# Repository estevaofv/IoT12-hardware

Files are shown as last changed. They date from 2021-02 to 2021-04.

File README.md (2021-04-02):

# Status

**Experimental. Do not replicate.**

**You should be present at all times when using this circuit in case something goes wrong.**

# IoT12-hardware
Schematic and PCB files of the IoT12 solder iron temperature controller for T12 tips.

My [Kicad library](https://github.com/atoomnetmarc/ATOOMNETKICAD) is used in this project.

Control Board:\
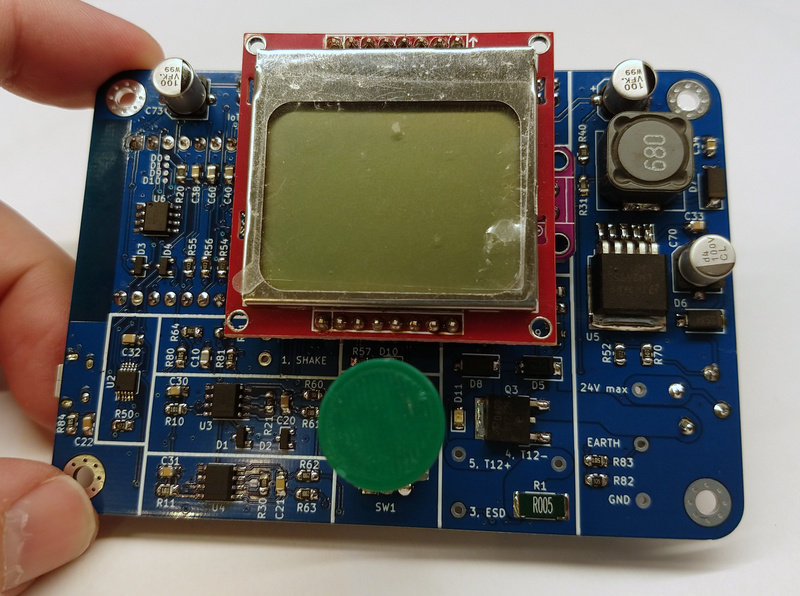
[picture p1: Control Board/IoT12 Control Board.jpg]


Power Supply:\
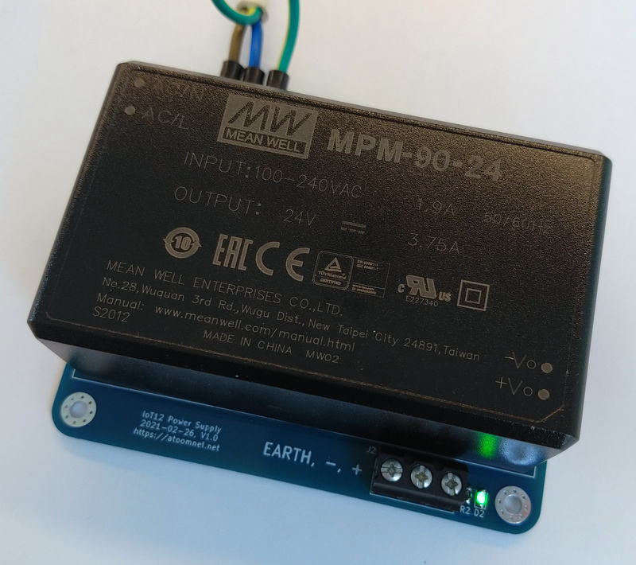
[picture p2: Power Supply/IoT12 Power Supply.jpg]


# Checklist

:ballot_box_with_check:Design schematic\
:ballot_box_with_check:Route V1 control board PCB\
:ballot_box_with_check:Slept a few days before ordering V1 control board PCB\
:ballot_box_with_check:Order V1 control board PCB\
:ballot_box_with_check:Made my first github repository\
:ballot_box_with_check:V1 control board PCB arrived\
:ballot_box_with_check:Solder V1 control board PCB and make assembly instructions\
:ballot_box_with_check:Observe that there is something wrong in schematic\
:ballot_box_with_check:Debug V1 control board PCB\
:ballot_box_with_check:Redesign control board PCB, add microcontroller\
:ballot_box_with_check:Order V2 control board PCB\
:ballot_box_with_check:Design power supply PCB\
:ballot_box_with_check:Order power supply PCB\
:ballot_box_with_check:V2 control board PCB and power supply PCB arrived\
:ballot_box_with_check:Solder V2 control board PCB and make assembly instructions\
:ballot_box_with_check:Solder V1 power supply PCB and make assembly instructions\
:black_square_button:Debug V2 control board PCB\
:ballot_box_with_check:Start making firmware\
:black_square_button:Finish first firmware version\
:black_square_button:...\
:black_square_button:profit

# Checklist V2.0 control PCB

Worky (after bodge fix)?

:ballot_box_with_check:SAMD21 debug LED\
:ballot_box_with_check:SAMD21 USB device\
:ballot_box_with_check:SAMD21 SWD\
:ballot_box_with_check:SAMD21 TP1/D0\
:ballot_box_with_check:SAMD21 TP2/D1\
:ballot_box_with_check:SAMD21 TP3/D9\
:ballot_box_with_check:SAMD21 TP4/D10\
:ballot_box_with_check:SAMD21 HEAT_INT\
:ballot_box_with_check:SAMD21 HEAT_PWM\
:ballot_box_with_check:SAMD21 I2C minion\
:ballot_box_with_check:SAMD21 I2S_GAIN0\
:ballot_box_with_check:SAMD21 I2S_GAIN1\
:ballot_box_with_check:SAMD21 I2S_SD\
:ballot_box_with_check:SAMD21 ADC_RDY\
:ballot_box_with_check:SAMD21 I2C ADC\
:ballot_box_with_check:SAMD21 I2C ADC NTC\
:ballot_box_with_check:SAMD21 I2C ADC TEMP\
:ballot_box_with_check:SAMD21 I2C ADC VIN\
:ballot_box_with_check:SAMD21 I2C ADC IRON_CURRENT\
:ballot_box_with_check:SAMD21 I2C EEPROM\
:ballot_box_with_check:SAMD21 ADC NTC\
:ballot_box_with_check:SAMD21 ADC TEMP\
:ballot_box_with_check:SAMD21 ADC VIN\
:ballot_box_with_check:SAMD21 ADC IRON_CURRENT\
:ballot_box_with_check:SAMD21 ADC AIN_COMP\
:ballot_box_with_check:SAMD21 AC AIN_COMP\
:ballot_box_with_check:ESP32 LCD_LED\
:ballot_box_with_check:ESP32 ROT_SW\
:ballot_box_with_check:ESP32 ROT_A\
:ballot_box_with_check:ESP32 ROT_B\
:ballot_box_with_check:ESP32 I2S\
:ballot_box_with_check:ESP32 I2C\
:ballot_box_with_check:ESP32 JTAG\
:ballot_box_with_check:ESP32 LCD\
:ballot_box_with_check:ESP32 HEAT_INT

# Changelog

**Control board PCB version V2.1**

- Swapped SDA/SCL I2C minion pins on heater controller.
- Swapped SDA/SCL I2C master pins on heater controller.
- Renamed PWM_HEAT to HEAT_PWM.
- Re-added MAX809S voltage monitor to keep ESP32 in reset if 3.3V is too low.
- Dimensioned F1 to 50% of Amax of T12-tip, see notes in schematic.
- Connected Vin ADC to after F1.

**Control board PCB version V2.0**

- Replace safety features by microcontroller.
- Heating control now done by microcontroller.
- Changed shape and layout of pcb.

**Control board PCB version V1.1**

- Added explanation to schematic about using matched resistors for the instrumentation amplifiers.
- Changed gain resistors of the instrumentation amplifiers as to keep Vout under 1V at full scale input.
- Added series diode to output of voltage monitor.
- Lowered value of C2-C5 from 10nF to 1nF.
- Added D9 and D10.
- Changed value of R9 from 100R to 1k
- Added circuit to shutdown heating in case of overheating tip.

**Control board PCB version V1.0**

- First version that got made into PCB form.

# Eratta

**Control board PCB version V2.1**

- No known erratum.

**Control board PCB version V2.0**

- I2C to heater controller not working. SDA/SCL are swapped. Swap them on the PCB near R55 and R56 to make the ESP32 communicate to the heater controller.
- A theme is developing :unamused:. I2C from the heater controller to the I2C EEPROM and ADC is not working. SDA/SCL are swapped. Swap them between R53, R54 and the heater controller on the bottom where the SDA/SCL traces run next to each other.
- ESP32 will lockup if power supply rise time is too slow.

**Control board PCB version V1.1**

- Overheating circuit not very stable. No fix.

**Control board PCB version V1.0**

- Silkscreen error in 'Solder iron connector'-block. '5, red, +.' and '4, black, ground.' are switched resulting in negative voltages for positive temperatures. Switch leads will solve this. Corrected in next PCB version.
- Gain of instrumentation amplifiers not correct.
- Programming by USB is impossible.
- Measuring temperature takes too long (20ms).



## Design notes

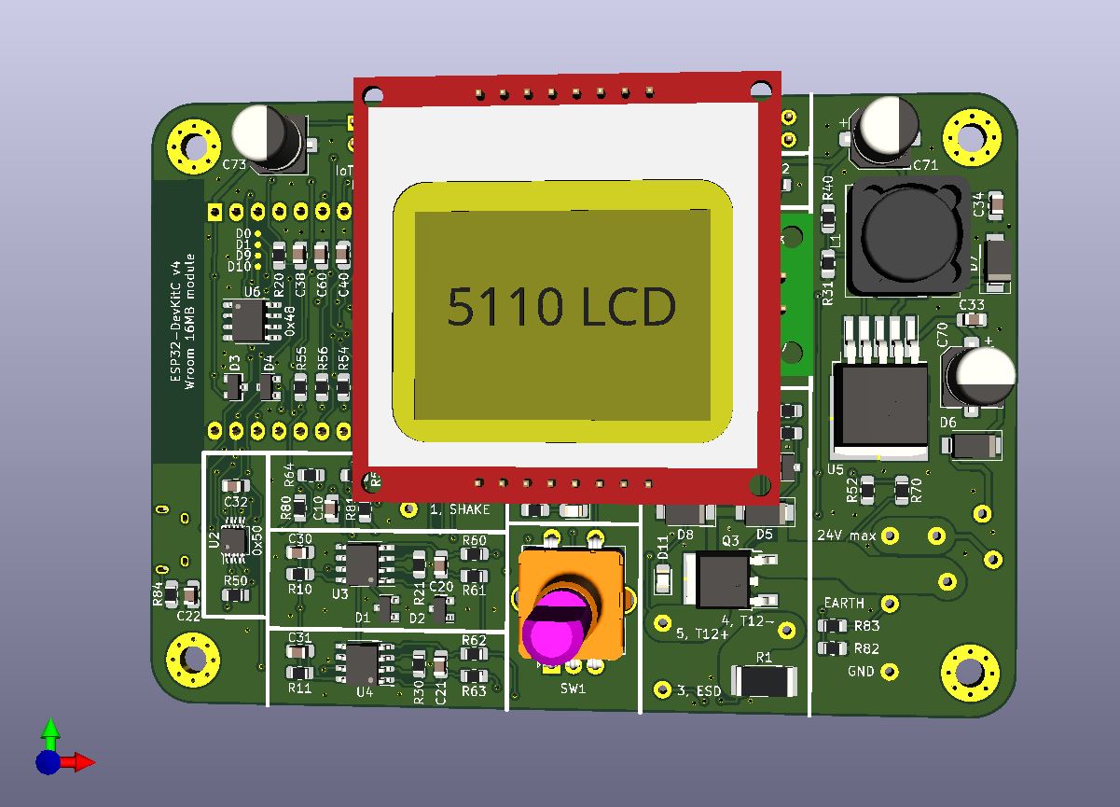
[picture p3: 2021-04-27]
Control Board/IoT12 Control Board-render.jpg

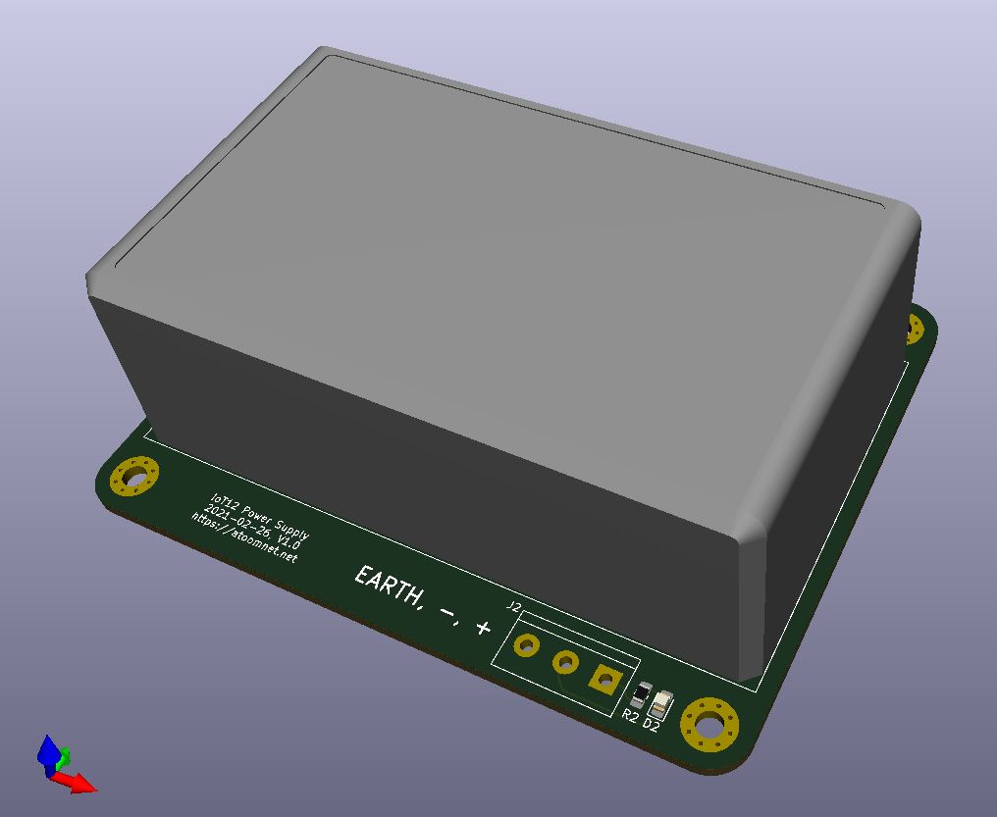
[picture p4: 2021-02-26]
Power Supply/IoT12 Power Supply-render.jpg

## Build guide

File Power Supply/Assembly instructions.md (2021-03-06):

# Solder

Solder components in the following order.
Use the [interactive BOM](bom/ibom.html) for values and positions of the components.

## Resistor

R2.

## Diode

D2.

## Screw terminal

J1, J2.

## Power supply

One off PS1, PS2 or PS3.

# Testing

⚡ ☠️ **Warning**! When testing you are  (mm|planck distances|inches) away from dangerous mains voltage. When touched it hurts the entire time you are dying. The bottom and top the PCB contain exposed tracks and screw terminals carrying mains voltage. Consult expert on how to handle mains voltages.

**You must use a wall socket that is protected by some kind of [Residual Current Device (RCD)](https://en.wikipedia.org/wiki/Residual-current_device)** that breaks the connection to mains voltage in the unfortunate event you touch live wires.

Place bottom of PCB on isolating material.

Connect leads of a mains cable to J1. Use the correct screw terminal for the correct mains line. If top of PCB is not clear enough, use labels on bottom of PCB and/or consult the PCB design files.

⚡ Connect the mains cable to the wall socket.

Notice the green LED lighting up. Now carefully measure the low voltage side on screw terminal J2. You should measure 24V volts (if you mounted a Mean Well MPM-90-24).

Disconnect the mains cable from the wall socket. Notice that the green LED is still lit. It will stop emitting light after some unit of time. The capacitors in the Mean Well power supply still contain some chare and are discharging slowly.

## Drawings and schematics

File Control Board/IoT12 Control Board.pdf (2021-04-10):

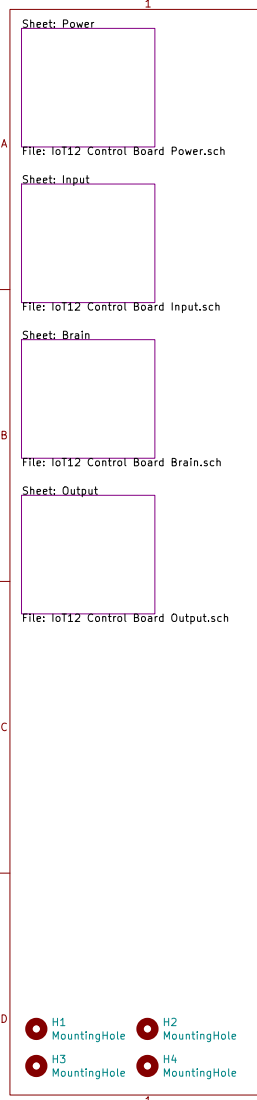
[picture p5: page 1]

File: IoT12 Control Board Input.sch Sheet: Power File: IoT12 Control Board Power.sch Sheet: Brain File: IoT12 Control Board Brain.sch Sheet: Output

File: IoT12 Control Board Output.sch H2MountingHole H4MountingHole H3MountingHole H1MountingHole

File: IoT12 Control Board.sch Sheet: /
Id: 1/5 Title: IoT12-hardware

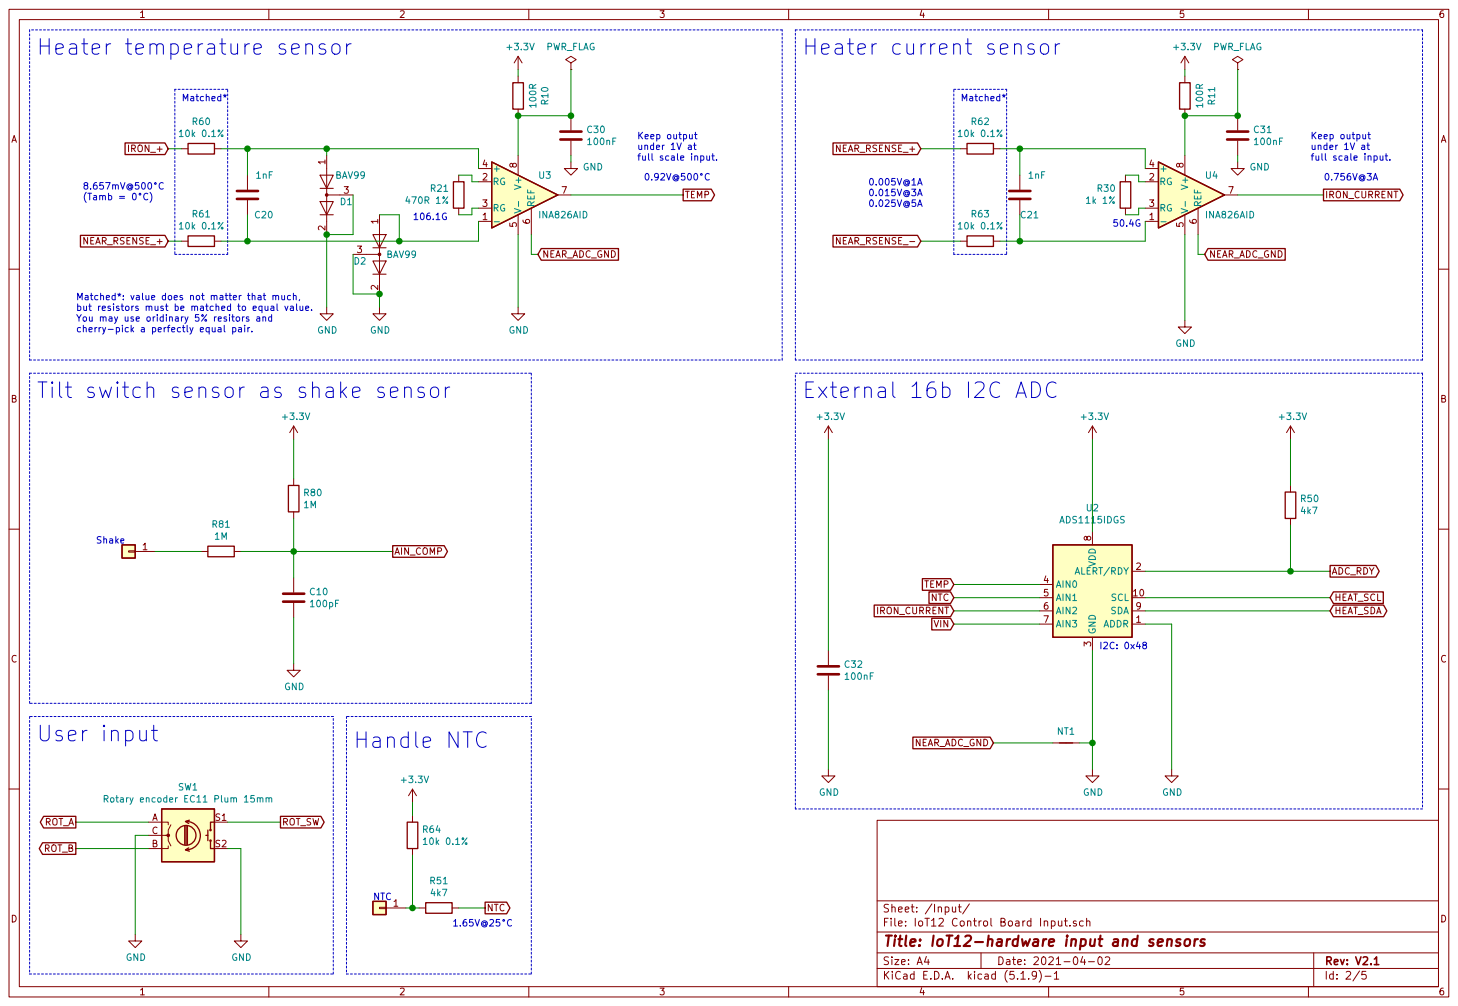
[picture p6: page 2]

Keep output under 1V at

Matched*: value does not matter that much, but resistors must be matched to equal value.

You may use oridinary 5% resitors and

1.65V@25°C Tilt switch sensor as shake sensor

Sheet: /Input/
File: IoT12 Control Board Input.sch
Id: 2/5 Title: IoT12-hardware input and sensors

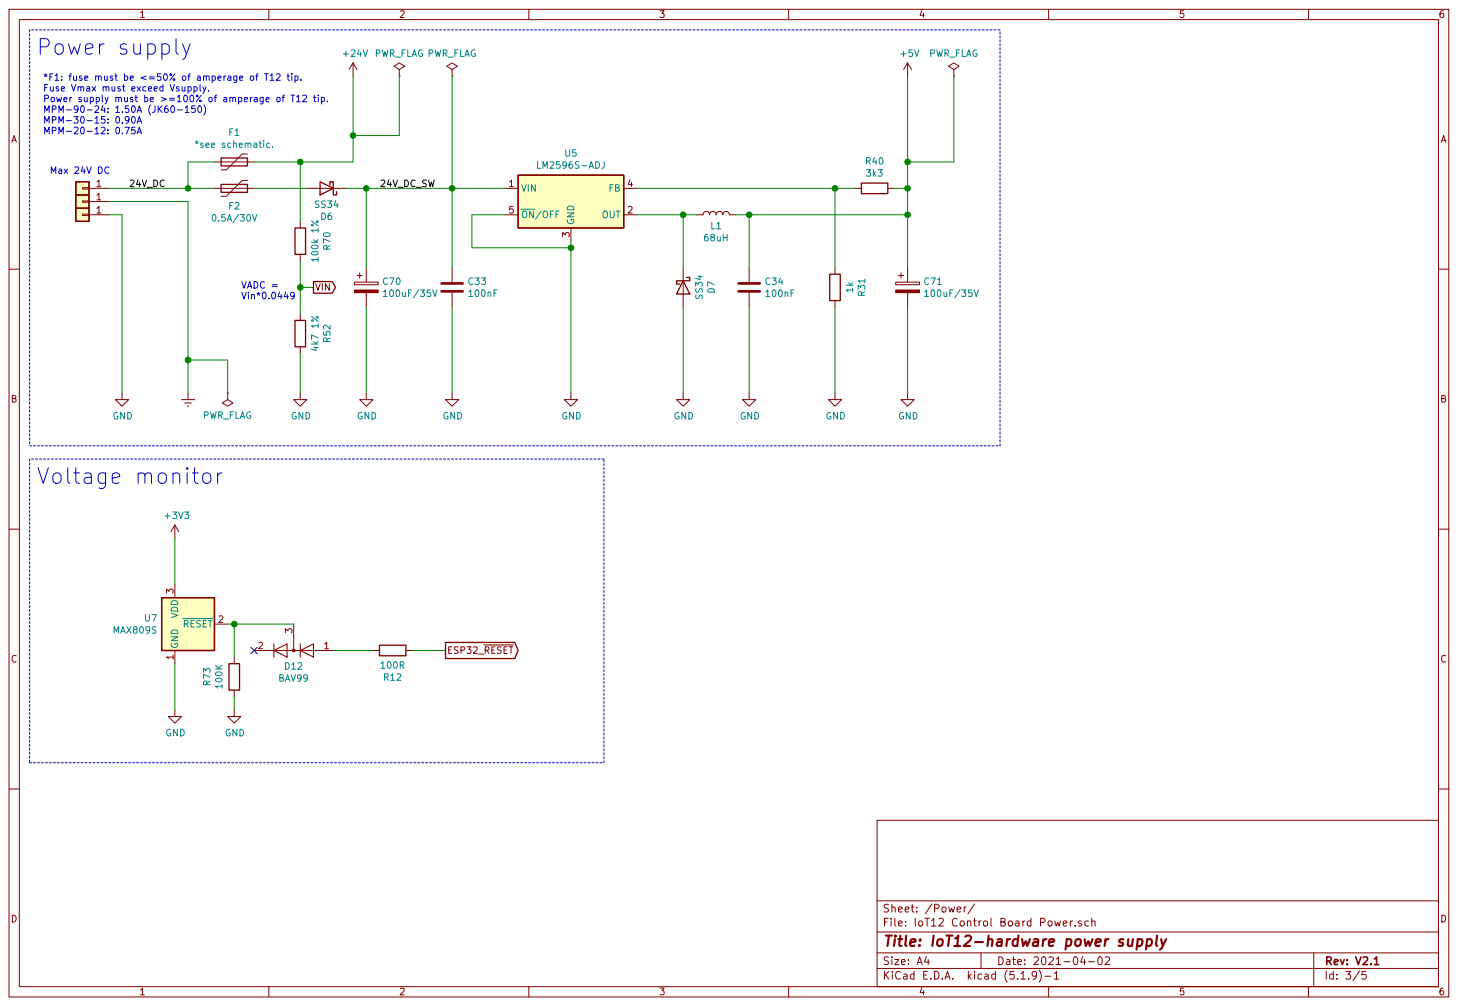
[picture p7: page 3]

MPM-90-24: 1.50A (JK60-150) MPM-30-15: 0.90A MPM-20-12: 0.75A Power supply
File: IoT12 Control Board Power.sch Sheet: /Power/ GND

*F1: fuse must be <=50% of amperage of T12 tip.
Fuse Vmax must exceed Vsupply.
Power supply must be >=100% of amperage of T12 tip.

VADC = Vin*0.0449 Max 24V DC Voltage monitor

Id: 3/5 Title: IoT12-hardware power supply

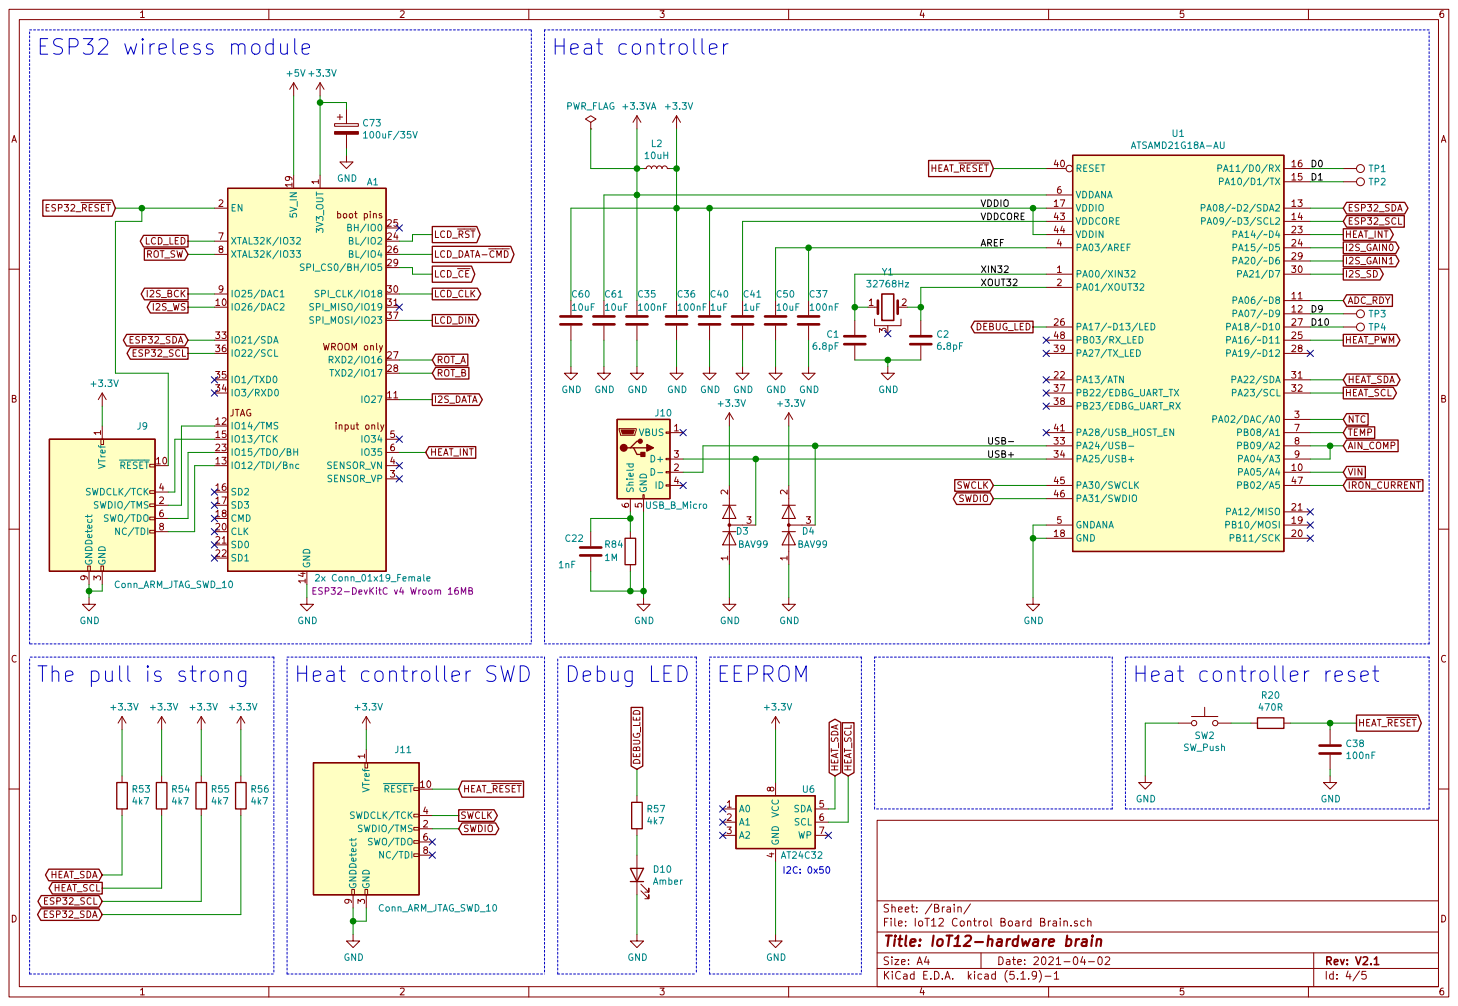
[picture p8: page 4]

3 SWDCLK/TCK 4 SWO/TDO 6 NC/TDI 8 GNDDetect 9

4 SDA 5 SCL 6 WP 7 VCC

File: IoT12 Control Board Brain.sch Sheet: /Brain/
Id: 4/5 Title: IoT12-hardware brain

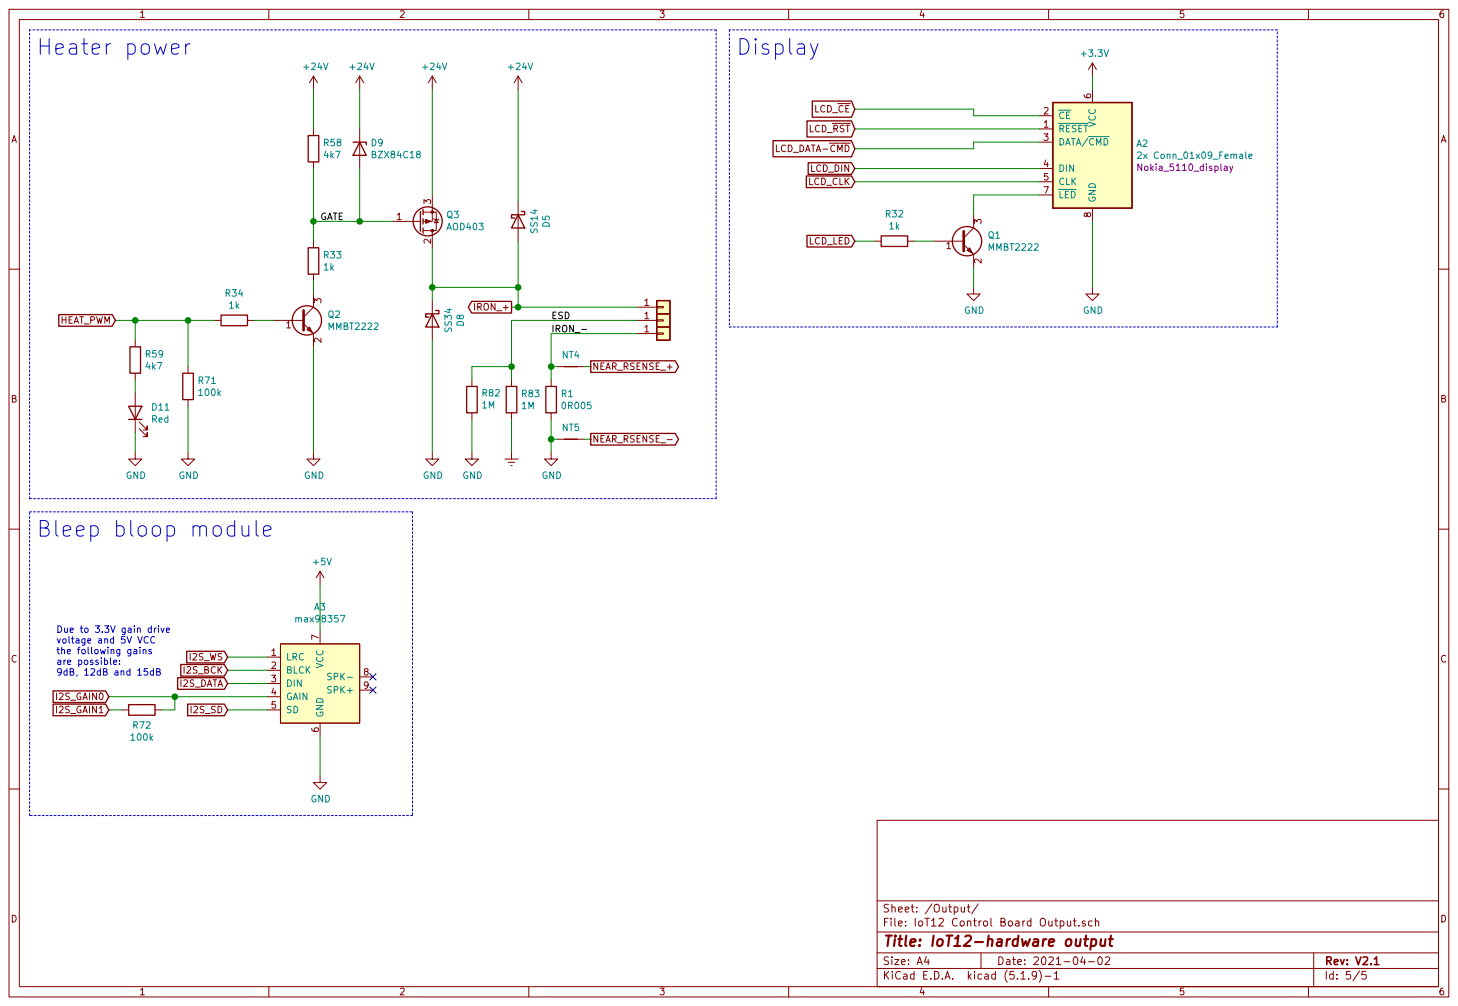
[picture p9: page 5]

are possible: 9dB, 12dB and 15dB Heater power

Due to 3.3V gain drive
voltage and 5V VCC
the following gains

Sheet: /Output/
File: IoT12 Control Board Output.sch
Id: 5/5 Title: IoT12-hardware output

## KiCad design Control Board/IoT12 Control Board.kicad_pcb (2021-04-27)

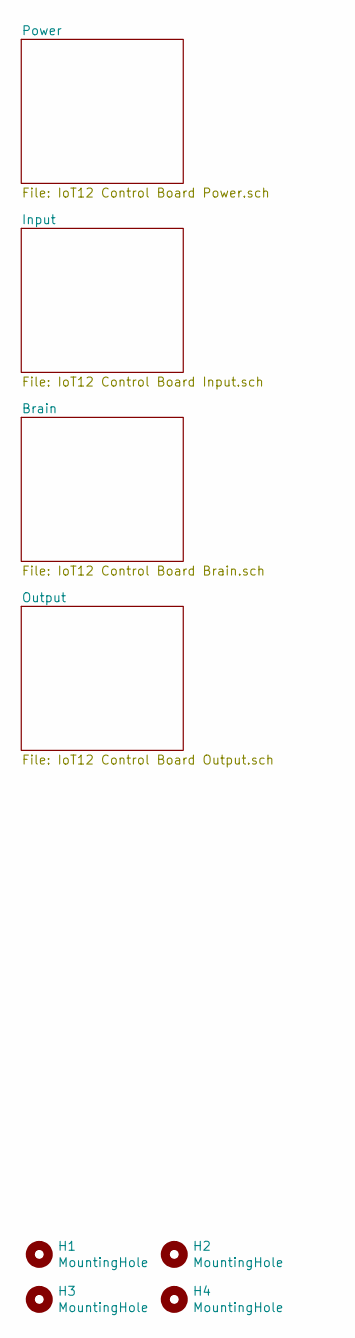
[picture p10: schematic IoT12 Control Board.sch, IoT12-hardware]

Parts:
H1, H2, H3, H4: MountingHole; MountingHole_3.2mm_M3_Pad_Via

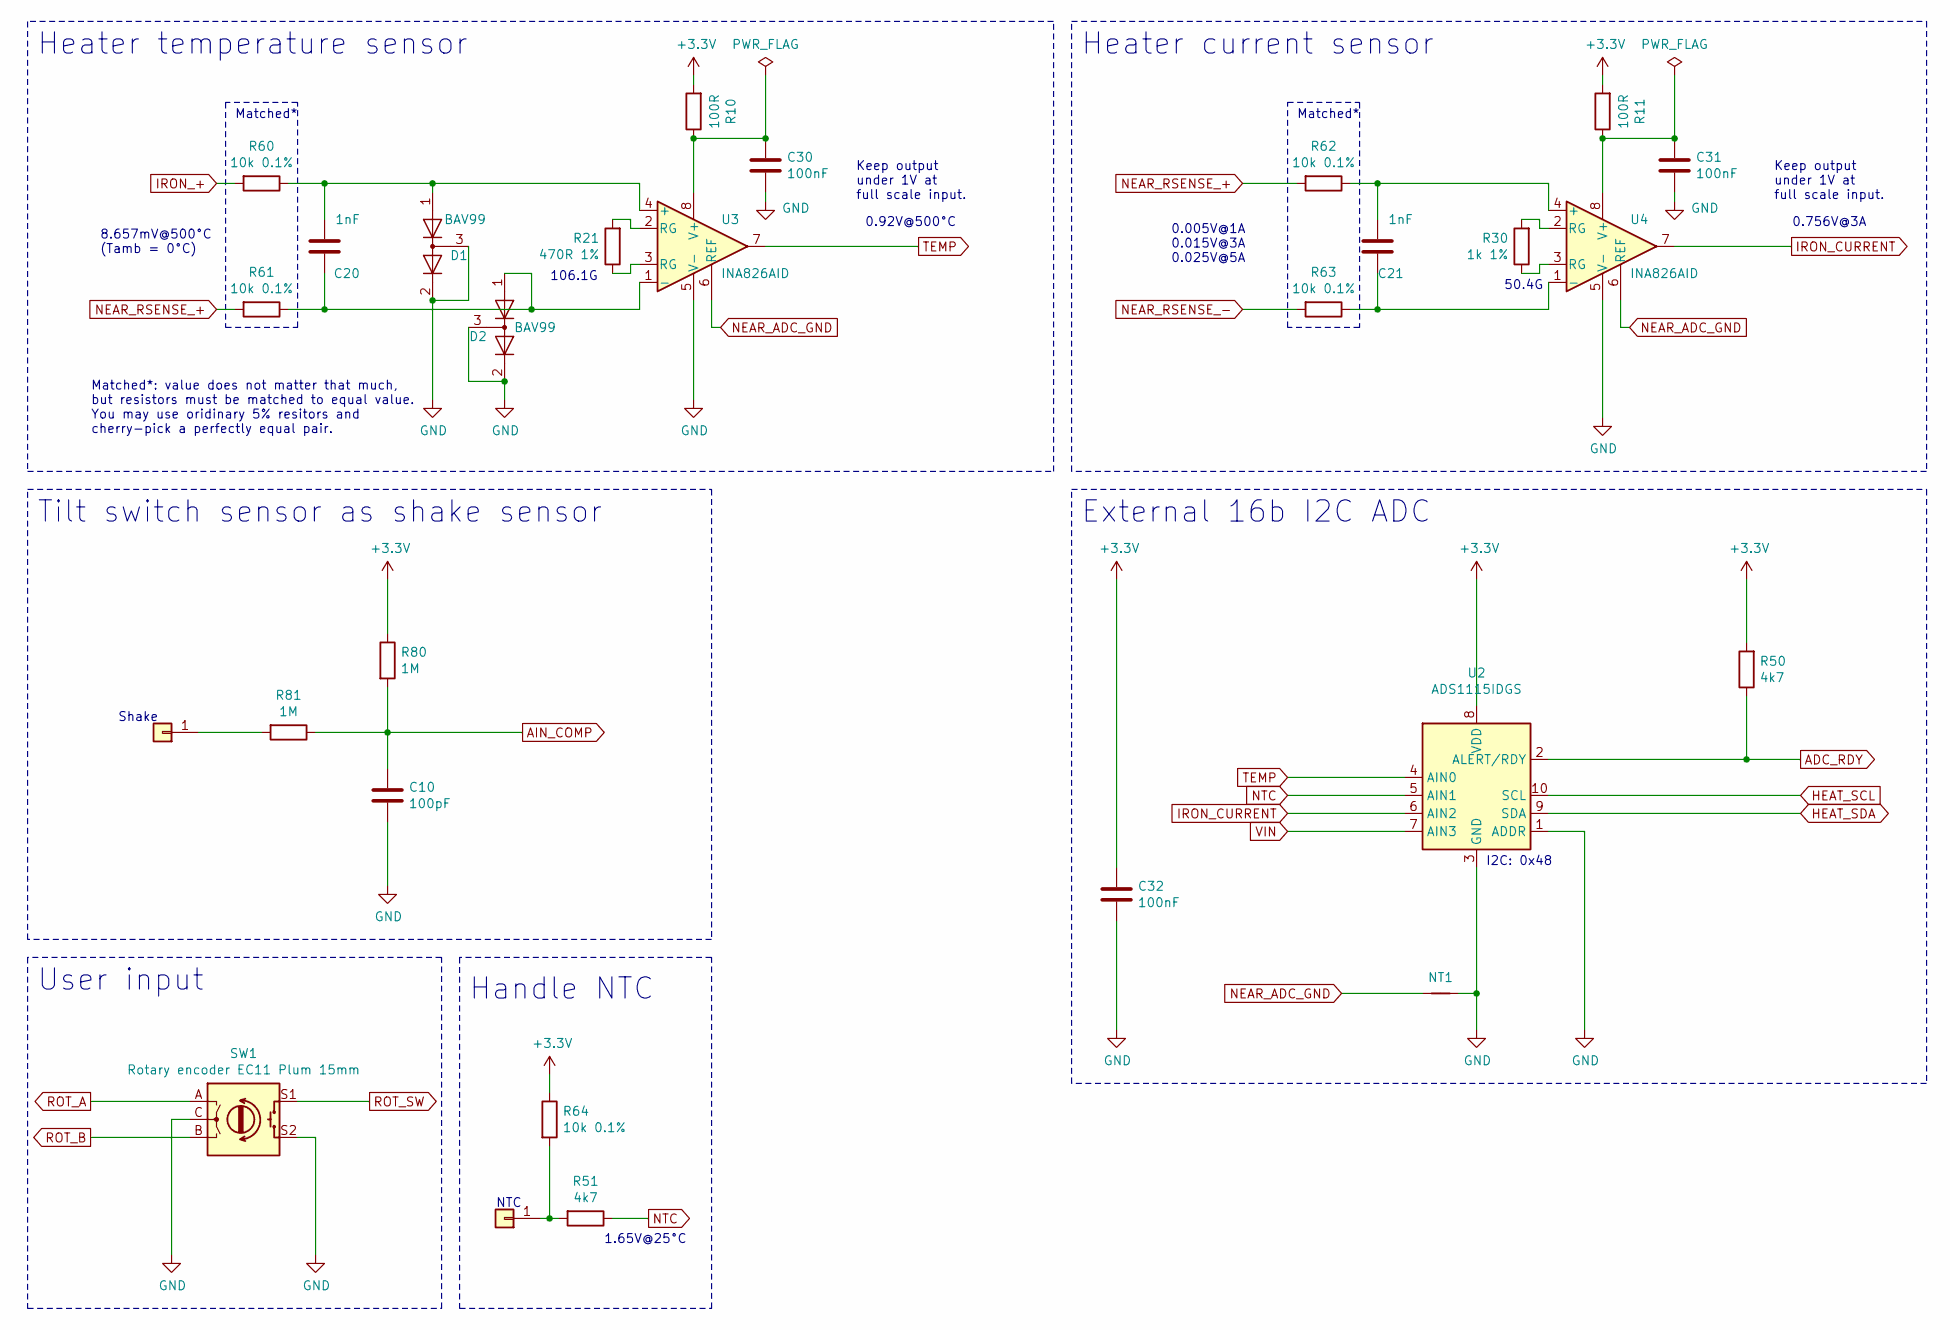
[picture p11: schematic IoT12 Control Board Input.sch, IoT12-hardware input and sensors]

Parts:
C10: 100pF; C_0805_2012Metric_Pad1.18x1.45mm_HandSolder
C20, C21: 1nF; C_0805_2012Metric_Pad1.18x1.45mm_HandSolder
C30, C31, C32: 100nF; C_0805_2012Metric_Pad1.18x1.45mm_HandSolder
D1, D2: BAV99; SOT-23
J1, J2: TestPoint_THTPad_D2.0mm_Drill1.0mm
NT1: NetTie-2_SMD_Pad0.25mm
R10, R11: 100R; R_0805_2012Metric_Pad1.20x1.40mm_HandSolder
R21: 470R 1%; R_0805_2012Metric_Pad1.20x1.40mm_HandSolder
R30: 1k 1%; R_0805_2012Metric_Pad1.20x1.40mm_HandSolder
R50, R51: 4k7; R_0805_2012Metric_Pad1.20x1.40mm_HandSolder
R60, R61, R62, R63, R64: 10k 0.1%; R_0805_2012Metric_Pad1.20x1.40mm_HandSolder
R80, R81: 1M; R_0805_2012Metric_Pad1.20x1.40mm_HandSolder
SW1: Rotary encoder EC11 Plum 15mm; RotaryEncoder_Alps_EC11E-Switch_Vertical_H20mm_CircularMoun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
U2: ADS1115IDGS; TSSOP-10_3x3mm_P0.5mm
U3, U4: INA826AID; SOIC-8_3.9x4.9mm_P1.27mm

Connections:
ADC_RDY: R50.1, U2.2 (ALERT/RDY); also elsewhere on the board
AIN_COMP: C10.1, R80.2, R81.1; also elsewhere on the board
GND: C10.2, C30.2, C31.2, C32.2, D1.2 (A), D1.3 (K), D2.2 (A), D2.3 (K), NT1.2, SW1.C, SW1.S2, U2.1 (ADDR), U2.3 (GND), U3.5 (V-), U4.5 (V-); also elsewhere on the board
HEAT_SCL: U2.10 (SCL); also elsewhere on the board
HEAT_SDA: U2.9 (SDA); also elsewhere on the board
IRON_+: R60.2; also elsewhere on the board
IRON_CURRENT: U2.6 (AIN2), U4.7; also elsewhere on the board
NEAR_ADC_GND: NT1.1, U3.6 (REF), U4.6 (REF)
NEAR_RSENSE_+: R61.2, R62.2; also elsewhere on the board
NEAR_RSENSE_-: R63.2; also elsewhere on the board
NTC: R51.1, U2.5 (AIN1); also elsewhere on the board
unnamed: C20.1, D1.1 (K), R60.1, U3.4 (+)
unnamed: C20.2, D2.1 (K), R61.1, U3.1 (-)
unnamed: C21.1, R62.1, U4.4 (+)
unnamed: C21.2, R63.1, U4.1 (-)
unnamed: C30.1, R10.1, U3.8 (V+)
unnamed: C31.1, R11.1, U4.8 (V+)
unnamed: J1.1, R81.2
unnamed: J2.1, R51.2, R64.2
unnamed: R21.1, U3.3 (RG)
unnamed: R21.2, U3.2 (RG)
unnamed: R30.1, U4.3 (RG)
unnamed: R30.2, U4.2 (RG)
ROT_A: SW1.A; also elsewhere on the board
ROT_B: SW1.B; also elsewhere on the board
ROT_SW: SW1.S1; also elsewhere on the board
TEMP: U2.4 (AIN0), U3.7; also elsewhere on the board
VIN: U2.7 (AIN3); also elsewhere on the board

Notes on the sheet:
User input
Heater temperature sensor
Heater current sensor
Handle NTC
NTC
Shake
Tilt switch sensor as shake sensor
50.4G
Matched*
0.005V@1A 0.015V@3A 0.025V@5A
106.1G
8.657mV@500°C (Tamb = 0°C)
0.92V@500°C
1.65V@25°C
Matched*: value does not matter that much, but resistors must be matched to equal value. You may use oridinary 5% resitors and cherry-pick a perfectly equal pair.
Keep output under 1V at full scale input.
0.756V@3A
External 16b I2C ADC
I2C: 0x48

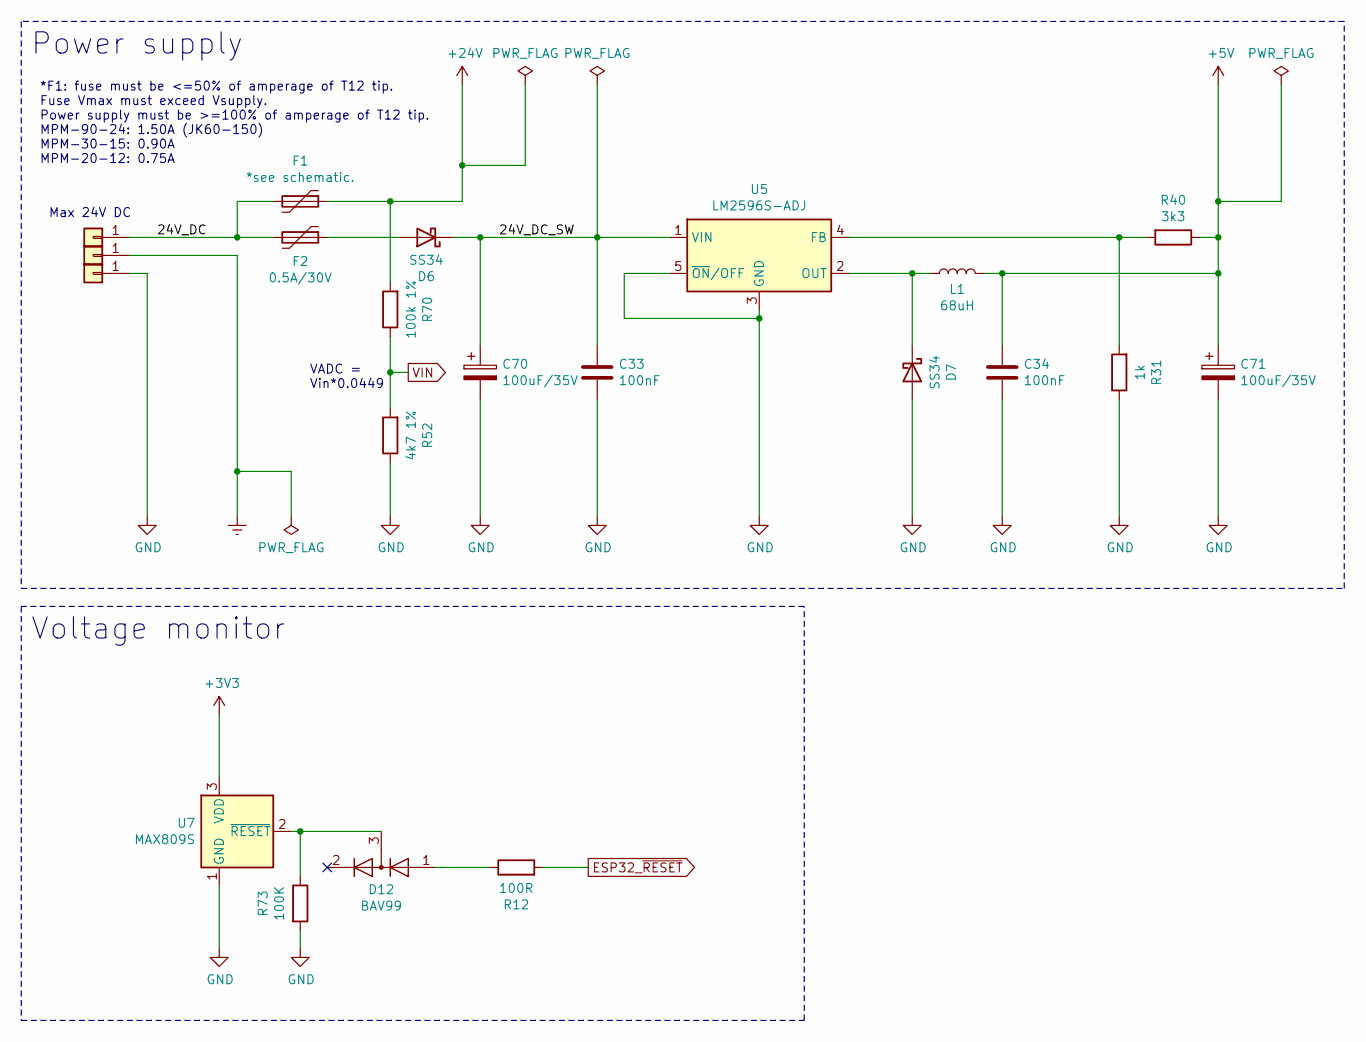
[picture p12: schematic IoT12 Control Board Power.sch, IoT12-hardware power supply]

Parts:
C33, C34: 100nF; C_0805_2012Metric_Pad1.18x1.45mm_HandSolder
C70, C71: 100uF/35V; CP_Elec_6.3x7.7
D6, D7: SS34; D_SMA
D12: BAV99; SOT-23
F1: *see schematic.; Fuse_Bourns_MF-RG1000
F2: 0.5A/30V; Fuse_Bourns_MF-RG400
J6, J7, J8: TestPoint_THTPad_D2.0mm_Drill1.0mm
L1: 68uH; L_12x12mm_H8mm
R12: 100R; R_0805_2012Metric_Pad1.20x1.40mm_HandSolder
R31: 1k; R_0805_2012Metric_Pad1.20x1.40mm_HandSolder
R40: 3k3; R_0805_2012Metric_Pad1.20x1.40mm_HandSolder
R52: 4k7 1%; R_0805_2012Metric_Pad1.20x1.40mm_HandSolder
R70: 100k 1%; R_0805_2012Metric_Pad1.20x1.40mm_HandSolder
R73: 100K; R_0805_2012Metric_Pad1.20x1.40mm_HandSolder
U5: LM2596S-ADJ; TO-263-5_TabPin3
U7: MAX809S; SOT-23

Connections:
+5V: C34.1, C71.1, L1.2, R40.1; also elsewhere on the board
+24V: F1.1, R70.2; also elsewhere on the board
/Power/24V_DC: F1.2, F2.2, J6.1
/Power/24V_DC_SW: C33.1, C70.1, D6.1 (K), U5.1 (VIN)
ESP32_~RESET: R12.2; also elsewhere on the board
Earth: J7.1; also elsewhere on the board
GND: C33.2, C34.2, C70.2, C71.2, D7.2 (A), J8.1, R31.1, R52.1, R73.2, U5.3 (GND), U5.5 (~ON~/OFF), U7.1 (GND); also elsewhere on the board
unnamed: D6.2 (A), F2.1
unnamed: D7.1 (K), L1.1, U5.2 (OUT)
unnamed: D12.1 (K), R12.1
unnamed: D12.3 (K), R73.1, U7.2 (~RESET)
unnamed: R31.2, R40.2, U5.4 (FB)
VIN: R52.2, R70.1; also elsewhere on the board

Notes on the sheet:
Power supply
VADC = Vin*0.0449
Max 24V DC
Voltage monitor
*F1: fuse must be <=50% of amperage of T12 tip. Fuse Vmax must exceed Vsupply. Power supply must be >=100% of amperage of T12 tip. MPM-90-24: 1.50A (JK60-150) MPM-30-15: 0.90A MPM-20-12: 0.75A

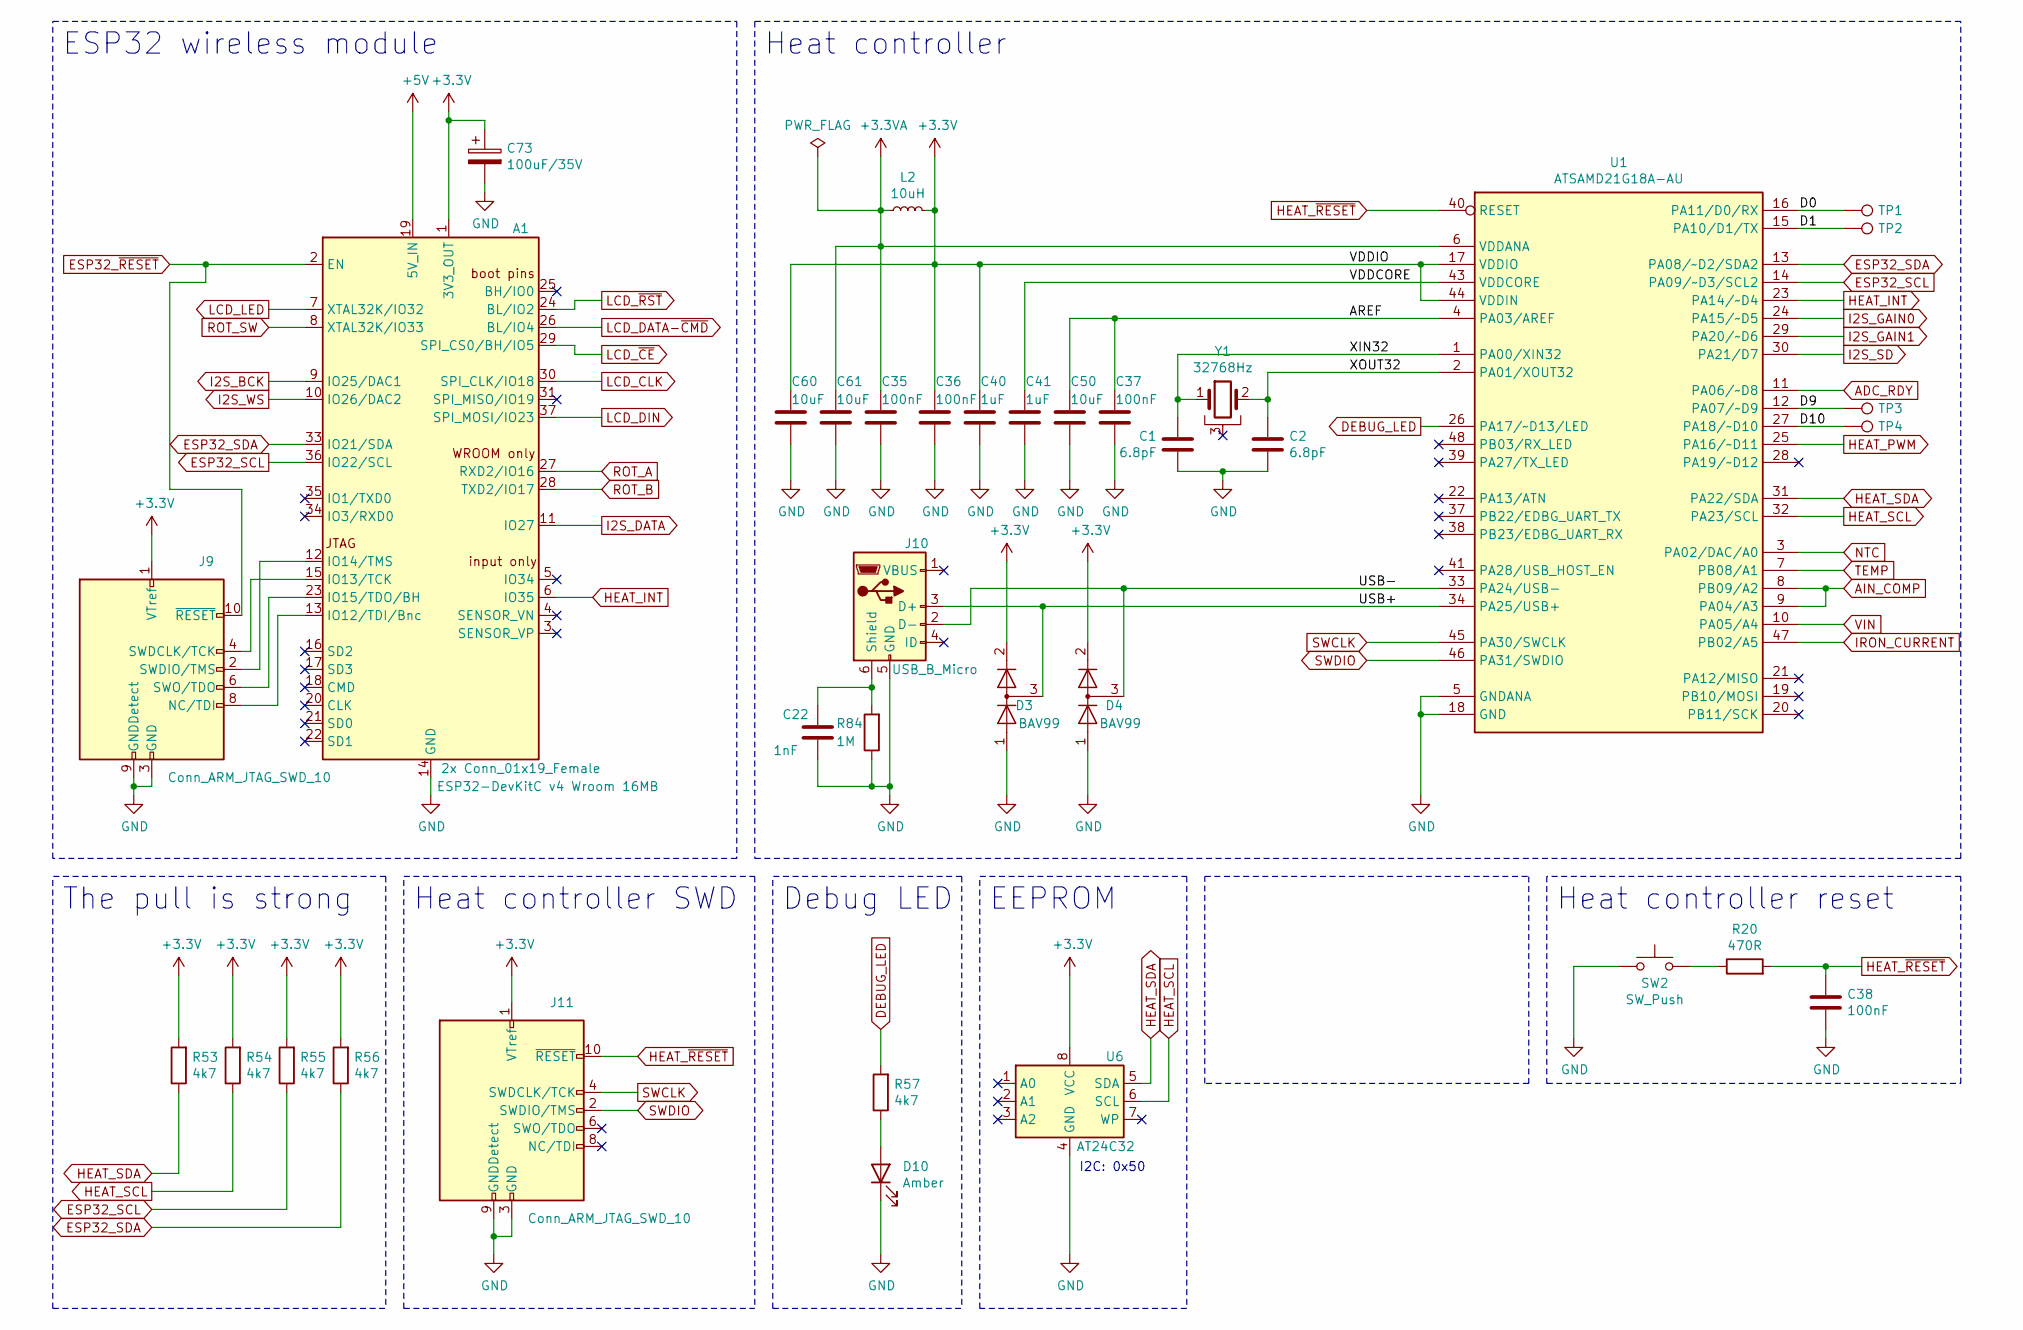
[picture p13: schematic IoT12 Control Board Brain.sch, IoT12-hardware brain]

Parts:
A1: 2x Conn_01x19_Female; ESP32-DevKitC
C1, C2: 6.8pF; C_0805_2012Metric_Pad1.18x1.45mm_HandSolder
C22: 1nF; C_0805_2012Metric_Pad1.18x1.45mm_HandSolder
C35, C36, C37, C38: 100nF; C_0805_2012Metric_Pad1.18x1.45mm_HandSolder
C40, C41: 1uF; C_0805_2012Metric_Pad1.18x1.45mm_HandSolder
C50, C60, C61: 10uF; C_0805_2012Metric_Pad1.18x1.45mm_HandSolder
C73: 100uF/35V; CP_Elec_6.3x7.7
D3, D4: BAV99; SOT-23
D10: Amber; LED_0805_2012Metric_Pad1.15x1.40mm_HandSolder
J9, J11: Conn_ARM_JTAG_SWD_10; PinHeader_2x05_P2.54mm_Vertical
J10: USB_B_Micro; USB_Micro-B_Amphenol_10118194_Horizontal
L2: 10uH; L_0805_2012Metric_Pad1.15x1.40mm_HandSolder
R20: 470R; R_0805_2012Metric_Pad1.20x1.40mm_HandSolder
R53, R54, R55, R56, R57: 4k7; R_0805_2012Metric_Pad1.20x1.40mm_HandSolder
R84: 1M; R_0805_2012Metric_Pad1.20x1.40mm_HandSolder
SW2: SW_Push; SW_SPST_CK_RS282G05A3
TP1, TP2, TP3, TP4: TestPoint; TestPoint_Pad_D0.75mm
U1: ATSAMD21G18A-AU; TQFP-48_7x7mm_P0.5mm
U6: AT24C32; SOIC-8_3.9x4.9mm_P1.27mm
Y1: 32768Hz; Crystal_C26-LF_D2.1mm_L6.5mm_Horizontal_1EP_style1

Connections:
+3.3VA: C35.1, C61.1, L2.1, U1.6 (VDDANA)
+5V: A1.19 (5V_IN); also elsewhere on the board
/Brain/AREF: C37.1, C50.1, U1.4 (PA03/AREF)
/Brain/D0: TP1.1, U1.16 (PA11/D0/RX)
/Brain/D1: TP2.1, U1.15 (PA10/D1/TX)
/Brain/D9: TP3.1, U1.12 (PA07/~~D9)
/Brain/D10: TP4.1, U1.27 (PA18/~~D10)
/Brain/USB+: D3.3 (K), J10.3 (D+), U1.34 (PA25/USB+)
/Brain/USB-: D4.3 (K), J10.2 (D-), U1.33 (PA24/USB-)
/Brain/VDDCORE: C41.1, U1.43 (VDDCORE)
/Brain/XIN32: C1.1, U1.1 (PA00/XIN32), Y1.1
/Brain/XOUT32: C2.1, U1.2 (PA01/XOUT32), Y1.2
ADC_RDY: U1.11 (PA06/~~D8); also elsewhere on the board
AIN_COMP: U1.8 (PB09/A2), U1.9 (PA04/A3); also elsewhere on the board
DEBUG_LED: R57.2, U1.26 (PA17/~~D13/LED)
ESP32_SCL: A1.36 (IO22/SCL), R55.1, U1.14 (PA09/~~D3/SCL2)
ESP32_SDA: A1.33 (IO21/SDA), R56.1, U1.13 (PA08/~~D2/SDA2)
ESP32_~RESET: A1.2 (EN), J9.10 (~RESET~); also elsewhere on the board
GND: A1.14 (GND), A1.32 (GND), A1.38 (GND), C1.2, C2.2, C22.2, C35.2, C36.2, C37.2, C38.2, C40.2, C41.2, C50.2, C60.2, C61.2, C73.2, D3.1 (K), D4.1 (K), D10.1 (K), J9.3 (GND), J9.5 (GND), J9.9 (GNDDetect), J10.5 (GND), J11.3 (GND), J11.5 (GND), J11.9 (GNDDetect), R84.1, SW2.1, U1.5 (GNDANA), U1.18 (GND), U1.35 (GND), U1.42 (GND), U6.4 (GND); also elsewhere on the board
HEAT_INT: A1.6 (IO35), U1.23 (PA14/~~D4)
HEAT_PWM: U1.25 (PA16/~~D11); also elsewhere on the board
HEAT_SCL: R54.1, U1.32 (PA23/SCL), U6.6 (SCL); also elsewhere on the board
HEAT_SDA: R53.1, U1.31 (PA22/SDA), U6.5 (SDA); also elsewhere on the board
HEAT_~RESET: C38.1, J11.10 (~RESET~), R20.2, U1.40 (RESET)
I2S_BCK: A1.9 (IO25/DAC1); also elsewhere on the board
I2S_DATA: A1.11 (IO27); also elsewhere on the board
I2S_GAIN0: U1.24 (PA15/~~D5); also elsewhere on the board
I2S_GAIN1: U1.29 (PA20/~~D6); also elsewhere on the board
I2S_SD: U1.30 (PA21/D7); also elsewhere on the board
I2S_WS: A1.10 (IO26/DAC2); also elsewhere on the board
IRON_CURRENT: U1.47 (PB02/A5); also elsewhere on the board
LCD_CLK: A1.30 (SPI_CLK/IO18); also elsewhere on the board
LCD_DATA-~CMD: A1.26 (BL/IO4); also elsewhere on the board
LCD_DIN: A1.37 (SPI_MOSI/IO23); also elsewhere on the board
LCD_LED: A1.7 (XTAL32K/IO32); also elsewhere on the board
LCD_~CE: A1.29 (SPI_CS0/BH/IO5); also elsewhere on the board
LCD_~RST: A1.24 (BL/IO2); also elsewhere on the board
NTC: U1.3 (PA02/DAC/A0); also elsewhere on the board
unnamed: A1.12 (IO14/TMS), J9.2 (SWDIO/TMS)
unnamed: A1.13 (IO12/TDI/Bnc), J9.8 (NC/TDI)
unnamed: A1.15 (IO13/TCK), J9.4 (SWDCLK/TCK)
unnamed: A1.23 (IO15/TDO/BH), J9.6 (SWO/TDO)
unnamed: C22.1, J10.6 (Shield), R84.2
unnamed: D10.2 (A), R57.1
unnamed: R20.1, SW2.2
ROT_A: A1.27 (RXD2/IO16); also elsewhere on the board
ROT_B: A1.28 (TXD2/IO17); also elsewhere on the board
ROT_SW: A1.8 (XTAL32K/IO33); also elsewhere on the board
SWCLK: J11.4 (SWDCLK/TCK), U1.45 (PA30/SWCLK)
SWDIO: J11.2 (SWDIO/TMS), U1.46 (PA31/SWDIO)
TEMP: U1.7 (PB08/A1); also elsewhere on the board
VIN: U1.10 (PA05/A4); also elsewhere on the board

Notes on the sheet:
ESP32 wireless module
Heat controller
Heat controller SWD
Heat controller reset
Debug LED
The pull is strong
EEPROM
I2C: 0x50

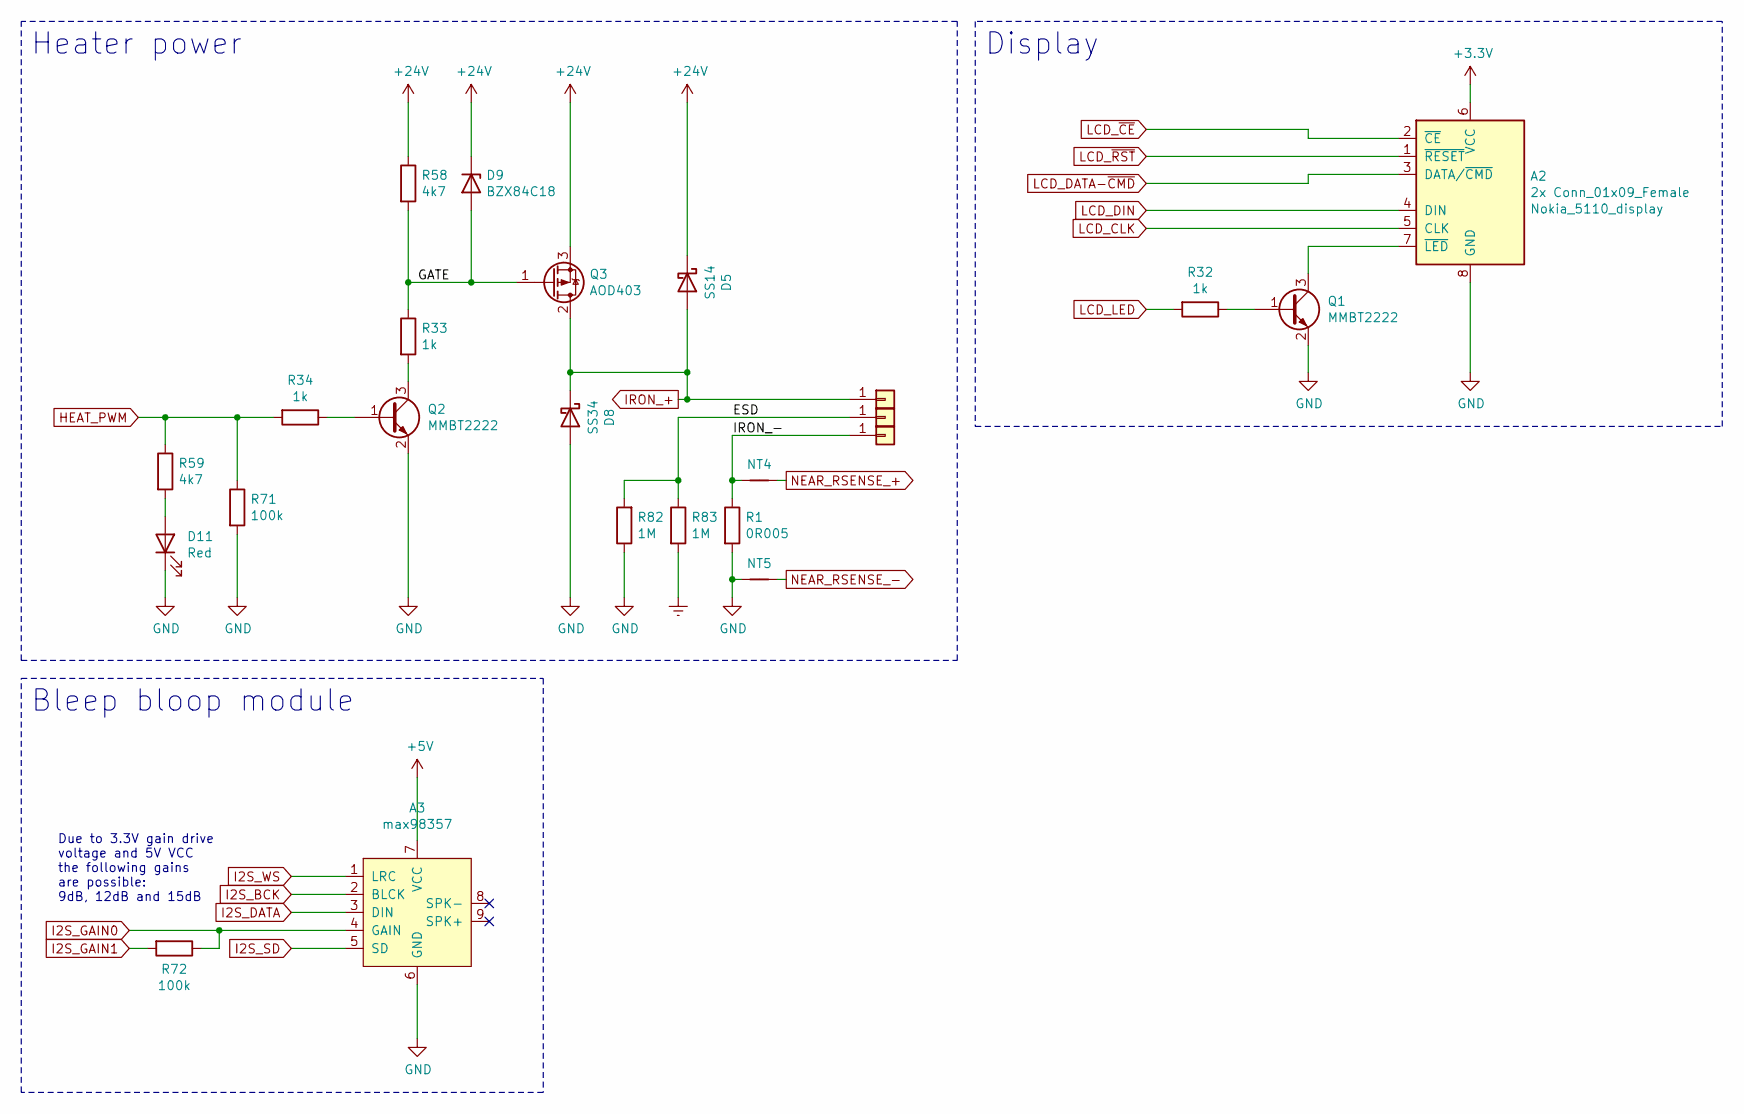
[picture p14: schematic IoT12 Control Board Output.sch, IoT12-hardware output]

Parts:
A2: 2x Conn_01x09_Female; Nokia_5110_display_module
A3: max98357
D5: SS14; D_SMA
D8: SS34; D_SMA
D9: BZX84C18; D_SOT-23_ANK
D11: Red; LED_0805_2012Metric_Pad1.15x1.40mm_HandSolder
J3, J4, J5: TestPoint_THTPad_D2.0mm_Drill1.0mm
NT4, NT5: NetTie-2_SMD_Pad0.25mm
Q1, Q2: MMBT2222; SOT-23
Q3: AOD403; TO-252-2
R1: 0R005; R_2512_6332Metric_Pad1.52x3.35mm_HandSolder
R32, R33, R34: 1k; R_0805_2012Metric_Pad1.20x1.40mm_HandSolder
R58, R59: 4k7; R_0805_2012Metric_Pad1.20x1.40mm_HandSolder
R71, R72: 100k; R_0805_2012Metric_Pad1.20x1.40mm_HandSolder
R82, R83: 1M; R_0805_2012Metric_Pad1.20x1.40mm_HandSolder

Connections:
+5V: A3.7 (VCC); also elsewhere on the board
+24V: D5.1 (K), D9.1 (K), Q3.3 (S), R58.1; also elsewhere on the board
/Output/ESD: J3.1, R82.2, R83.1
/Output/GATE: D9.2 (A), Q3.1 (G), R33.1, R58.2
/Output/IRON_-: J4.1, NT4.1, R1.1
Earth: R83.2; also elsewhere on the board
GND: A2.8 (GND), A3.6 (GND), D8.2 (A), D11.1 (K), NT5.1, Q1.2 (E), Q2.2 (E), R1.2, R71.2, R82.1; also elsewhere on the board
HEAT_PWM: R34.2, R59.1, R71.1; also elsewhere on the board
I2S_BCK: A3.2 (BLCK); also elsewhere on the board
I2S_DATA: A3.3 (DIN); also elsewhere on the board
I2S_GAIN0: A3.4 (GAIN), R72.1; also elsewhere on the board
I2S_GAIN1: R72.2; also elsewhere on the board
I2S_SD: A3.5 (SD); also elsewhere on the board
I2S_WS: A3.1 (LRC); also elsewhere on the board
IRON_+: D5.2 (A), D8.1 (K), J5.1, Q3.2 (D); also elsewhere on the board
LCD_CLK: A2.5 (CLK); also elsewhere on the board
LCD_DATA-~CMD: A2.3 (DATA/~CMD); also elsewhere on the board
LCD_DIN: A2.4 (DIN); also elsewhere on the board
LCD_LED: R32.2; also elsewhere on the board
LCD_~CE: A2.2 (~CE); also elsewhere on the board
LCD_~RST: A2.1 (~RESET); also elsewhere on the board
NEAR_RSENSE_+: NT4.2; also elsewhere on the board
NEAR_RSENSE_-: NT5.2; also elsewhere on the board
unnamed: A2.7 (~LED), Q1.3 (C)
unnamed: D11.2 (A), R59.2
unnamed: Q1.1 (B), R32.1
unnamed: Q2.1 (B), R34.1
unnamed: Q2.3 (C), R33.2

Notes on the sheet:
Display
Heater power
Bleep bloop module
Due to 3.3V gain drive voltage and 5V VCC the following gains are possible: 9dB, 12dB and 15dB

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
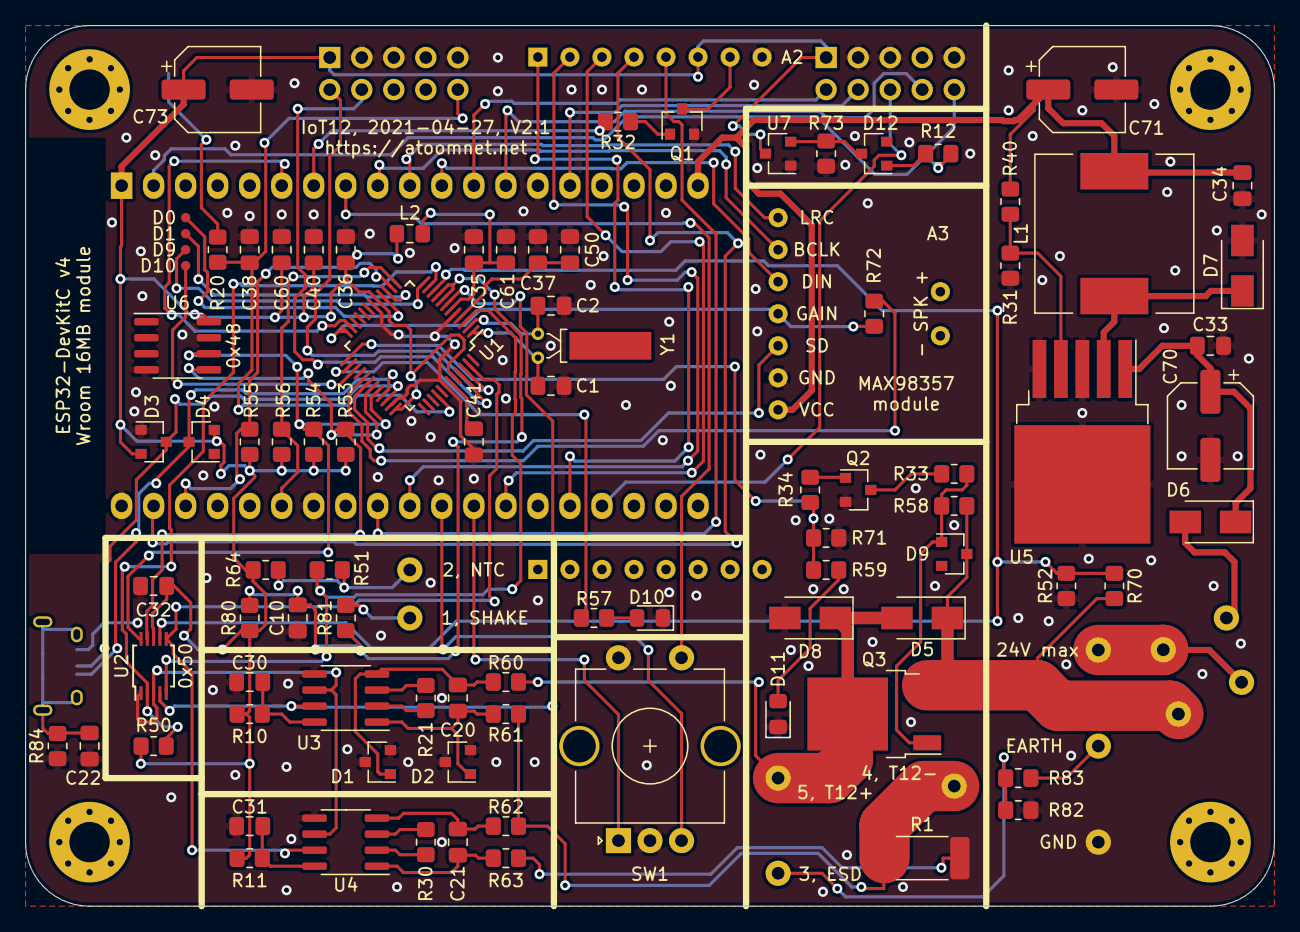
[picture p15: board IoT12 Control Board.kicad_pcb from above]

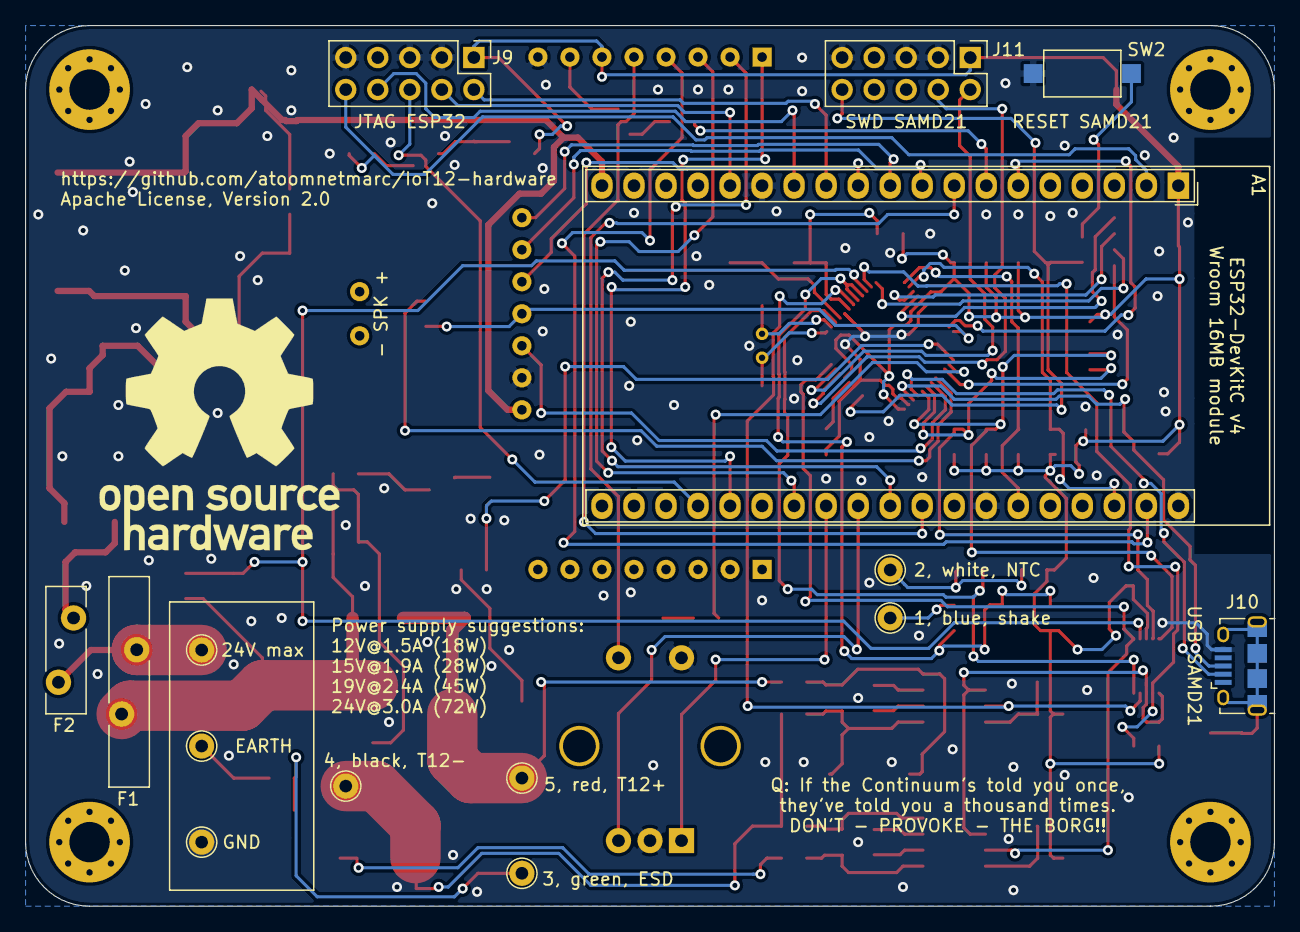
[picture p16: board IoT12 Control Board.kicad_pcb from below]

Board: 2 copper layers, 99.1 x 69.8 mm, 113 parts (15 on the bottom side), 86 nets.

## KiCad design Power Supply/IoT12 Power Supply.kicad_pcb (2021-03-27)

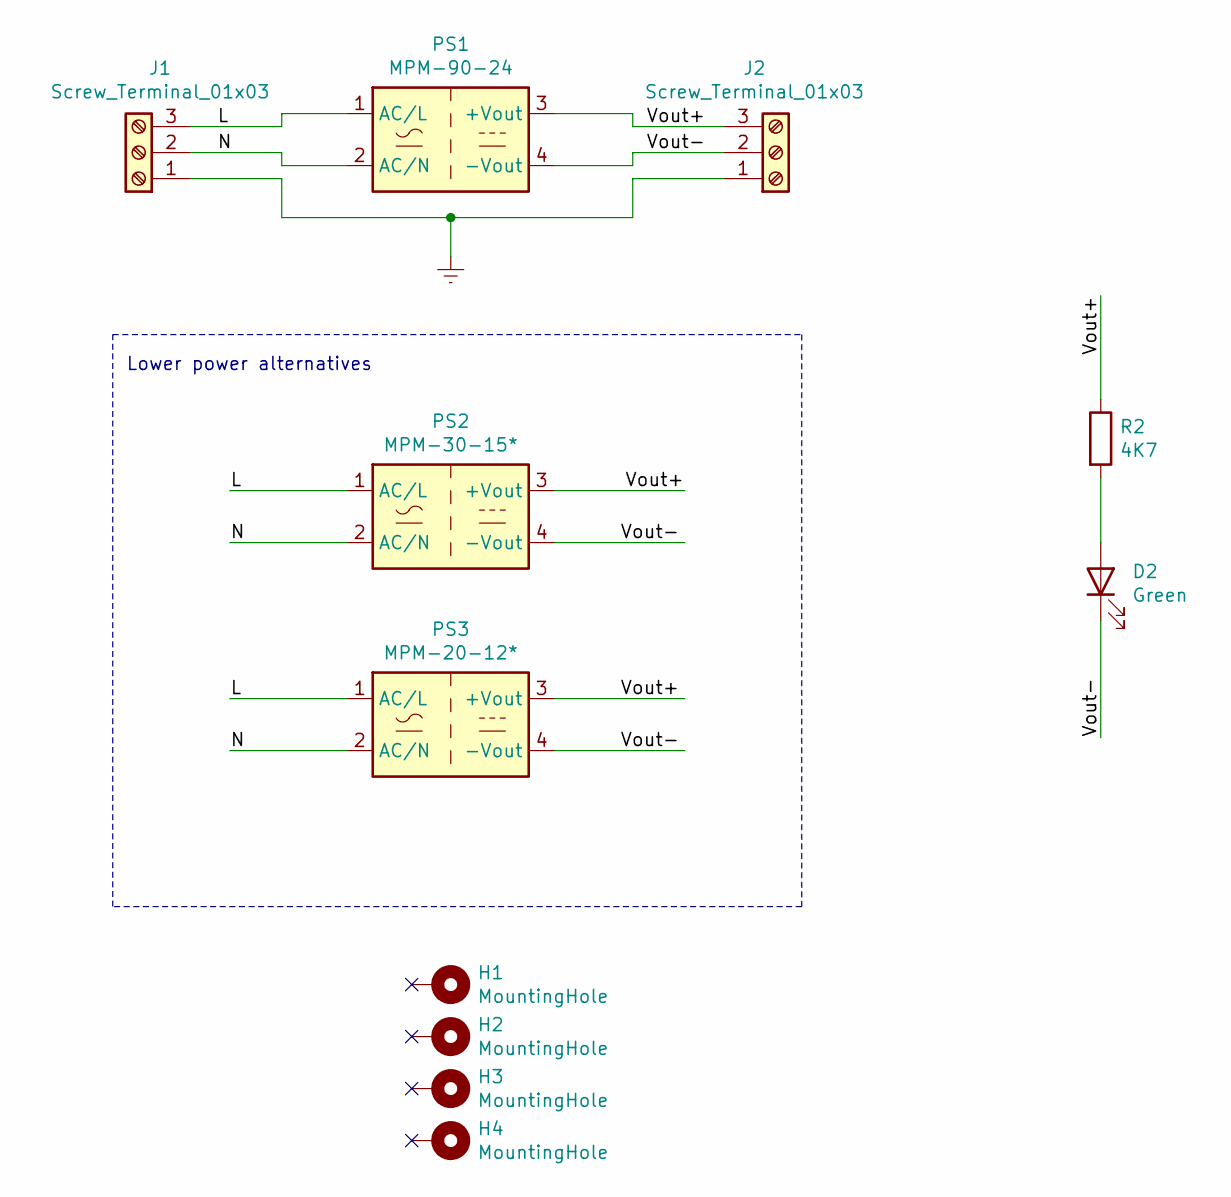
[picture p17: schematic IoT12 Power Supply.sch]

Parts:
D2: Green; LED_0805_2012Metric_Pad1.15x1.40mm_HandSolder
H1, H2, H3, H4: MountingHole; MountingHole_3.2mm_M3_Pad_Via
J1, J2: Screw_Terminal_01x03; TerminalBlock_bornier-3_P5.08mm
PS1: MPM-90-24; Converter_ACDC_MeanWell_MPM-90-xx_THT
PS2: MPM-30-15*; Converter_ACDC_MeanWell_MPM-30-xx_THT
PS3: MPM-20-12*; Converter_ACDC_MeanWell_MPM-20-xx_THT
R2: 4K7; R_0805_2012Metric_Pad1.20x1.40mm_HandSolder

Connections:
/L: J1.3, PS1.1 (AC/L), PS2.1 (AC/L), PS3.1 (AC/L)
/N: J1.2, PS1.2 (AC/N), PS2.2 (AC/N), PS3.2 (AC/N)
/Vout+: J2.3, PS1.3 (+Vout), PS2.3 (+Vout), PS3.3 (+Vout), R2.1
/Vout-: D2.1 (K), J2.2, PS1.4 (-Vout), PS2.4 (-Vout), PS3.4 (-Vout)
Earth: J1.1, J2.1
unnamed: D2.2 (A), R2.2

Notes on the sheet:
Lower power alternatives

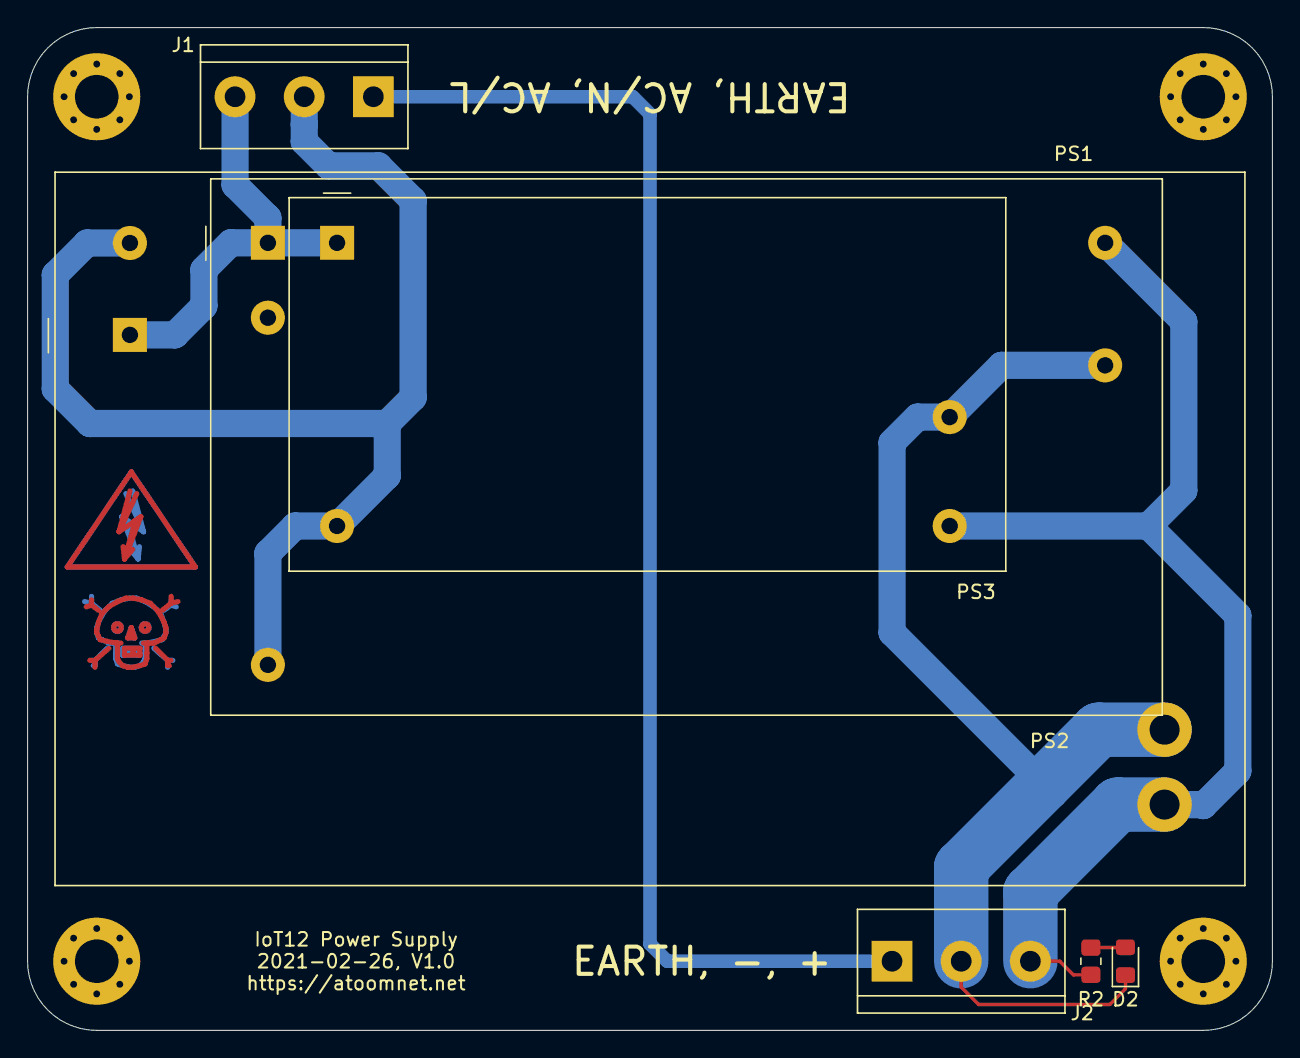
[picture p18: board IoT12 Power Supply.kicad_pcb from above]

Board: 2 copper layers, 91.4 x 73.7 mm, 11 parts (0 on the bottom side), 6 nets.

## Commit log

2021-01-29 Updated rotary encoder model#
    [IoT12.kicad_pcb, IoT12.sch]
2021-01-29 PCB has arrived
2021-01-29 Added assembly instructions
2021-01-29 Update Assembly instructions.md
2021-01-30 PCB not working. Added warning.
2021-02-07 PCB V1.1
    [IoT12-B_Cu.gbr, IoT12-B_Mask.gbr, IoT12-B_SilkS.gbr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]
2021-02-09 Updated schematic and pcb.
    [IoT12-B_Cu.gbr, IoT12-B_Mask.gbr, IoT12-B_SilkS.gbr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]
2021-02-13 Schematic split into multiple sheets.
    [Brain.sch, Input.sch, IoT12.kicad_pcb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]
2021-02-13 Added overheat protection that works, but very noisy.
    [Brain.sch, Input.sch, IoT12.kicad_pcb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]
2021-02-13 Start of V2.0
    [Output.sch]
2021-02-21 V2.0 pcb.
    [Brain.sch, Input.sch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]
2021-02-24 Ordered the V2.0 pcb
2021-02-26 Move control board to subdirectory.
    [Brain.sch, Input.sch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]
2021-02-26 Designed Power Supply PCB.
    [IoT12 Power Supply-B_Cu.gbr, IoT12 Power Supply-B_Mask.gbr, IoT12 Power Supply-B_SilkS.gbr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]
2021-03-06 Changed license to permissive.
    [IoT12 Power Supply-B_Cu.gbr, IoT12 Power Supply-B_Mask.gbr, IoT12 Power Supply-B_SilkS.gbr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]
2021-03-06 Oooo, pcbs arrived.
2021-03-06 Rotated J1, J2.
    [IoT12 Power Supply-B_Cu.gbr, IoT12 Power Supply-B_Mask.gbr, IoT12 Power Supply-B_SilkS.gbr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]
2021-03-06 Power supply done.
2021-03-06 Soldered V2.0 pcb.
    [Brain.sch, IoT12.kicad_pcb]
2021-03-07 Start of V2.1 PCB.
    [Brain.sch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]
2021-03-08 Added SDA2/SCL2 labels on SAMD21.
    [Brain.sch, Input.sch, IoT12.kicad_pcb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]
2021-03-12 Samd21 D2, D4 where swapped in symbol. No pcb change.
    [Brain.sch, Input.sch, IoT12.kicad_pcb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]
2021-03-12 Not all GAIN combinations are possible.
    [Output.sch]
2021-03-12 Corrected errors.
    [Output.sch]
2021-03-13 More erratum.
    [Brain.sch, Input.sch, IoT12.kicad_pcb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]
2021-03-13 Rename control board project files.
    [IoT12 Control Board Brain.sch, IoT12 Control Board Input.sch, IoT12 Control Board Output.sch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]
2021-03-13 Added I2C addresses to silkscreen and schematic.
    [IoT12 Control Board Brain.sch, IoT12 Control Board.kicad_pcb]
2021-03-15 More testing and re-added voltage monitor.
    [IoT12 Control Board Brain.sch, IoT12 Control Board Power.sch, IoT12 Control Board.kicad_pcb]
2021-03-27 Updated pin1 marker of PS2.
    [IoT12 Power Supply-B_Cu.gbr, IoT12 Power Supply-B_Mask.gbr, IoT12 Power Supply-B_SilkS.gbr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]
2021-03-27 Changed value R82.
    [IoT12 Control Board Output.sch, IoT12 Control Board.kicad_pcb]
2021-03-27 Updated revision date.
    [IoT12 Control Board Brain.sch, IoT12 Control Board Input.sch, IoT12 Control Board Output.sch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]
2021-03-28 Revert R82 back to 1M.
    [IoT12 Control Board Brain.sch, IoT12 Control Board Input.sch, IoT12 Control Board Output.sch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]
2021-03-28 Finetuned assembly instructions.
2021-04-02 V2.1 changes.
    [IoT12 Control Board Brain.sch, IoT12 Control Board Input.sch, IoT12 Control Board Output.sch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]
2021-04-10 Added ~RESET pulldown resistor.
    [IoT12 Control Board Brain.sch, IoT12 Control Board Power.sch, IoT12 Control Board.kicad_pcb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]
2021-04-24 updated lcd footprint
    [IoT12 Control Board.kicad_pcb]
2021-04-27 Changed some footprints to that have 3d models.
    [IoT12 Control Board Brain.sch, IoT12 Control Board Input.sch, IoT12 Control Board Output.sch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]
2021-04-27 Changed usb connector to one that has a 3d model.
    [IoT12 Control Board Brain.sch, IoT12 Control Board.kicad_pcb]

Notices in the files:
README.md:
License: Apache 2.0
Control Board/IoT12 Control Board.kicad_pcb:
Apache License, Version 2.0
